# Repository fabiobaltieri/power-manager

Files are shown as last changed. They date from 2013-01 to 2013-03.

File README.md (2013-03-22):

USB Power Manager
=================

http://fabiobaltieri.com/2013/03/22/power-manager/

This project is an USB power controller, and allows to control the power lines
of two USB ports and a generic supply line.

Main features:
- Two controllable USB ports (5V)
- One controllable generic supply line, up to 26V
- Overcurrent protection for USB ports
- Voltage and current measurement on both USB and power ports, before and after
  the switch
- Two additional independent relay lines (for switch simulation)
- Programmable delayed switching sequence for all ports

License
-------

This program is free software: you can redistribute it and/or modify
it under the terms of the GNU General Public License as published by
the Free Software Foundation, either version 2 of the License, or
(at your option) any later version.

Contents
--------

    COPYING      text version of the GPL
    README       this file
    bootloader/  source directory for bootloader
    bootloader-util/ source directory for bootloader utility (bootloadHID)
    commandline/ source directory for the "pm" utility
    firmware/    source directory for main firmware
    hardware/    source directory for the hardware design

Firmware and Bootloader
-----------------------

Building requires an avr-gcc toolchain, in the firmware/ or bootloader/
directory, to build run:

    make

Flashing the firmware on the device requires avrdude and a compatible hardware
programmer. Default configuration is stored at the beginning of the Makefile.
To program with the default configuration, run:

    make flash

Fuses can be configured running:

    make fuses

To program the main firmware from the bootloader, use the command:

    make boot

Hardware
--------

All hardware files (schematic, layout and libraries) are in CadSoft Eagle
format.

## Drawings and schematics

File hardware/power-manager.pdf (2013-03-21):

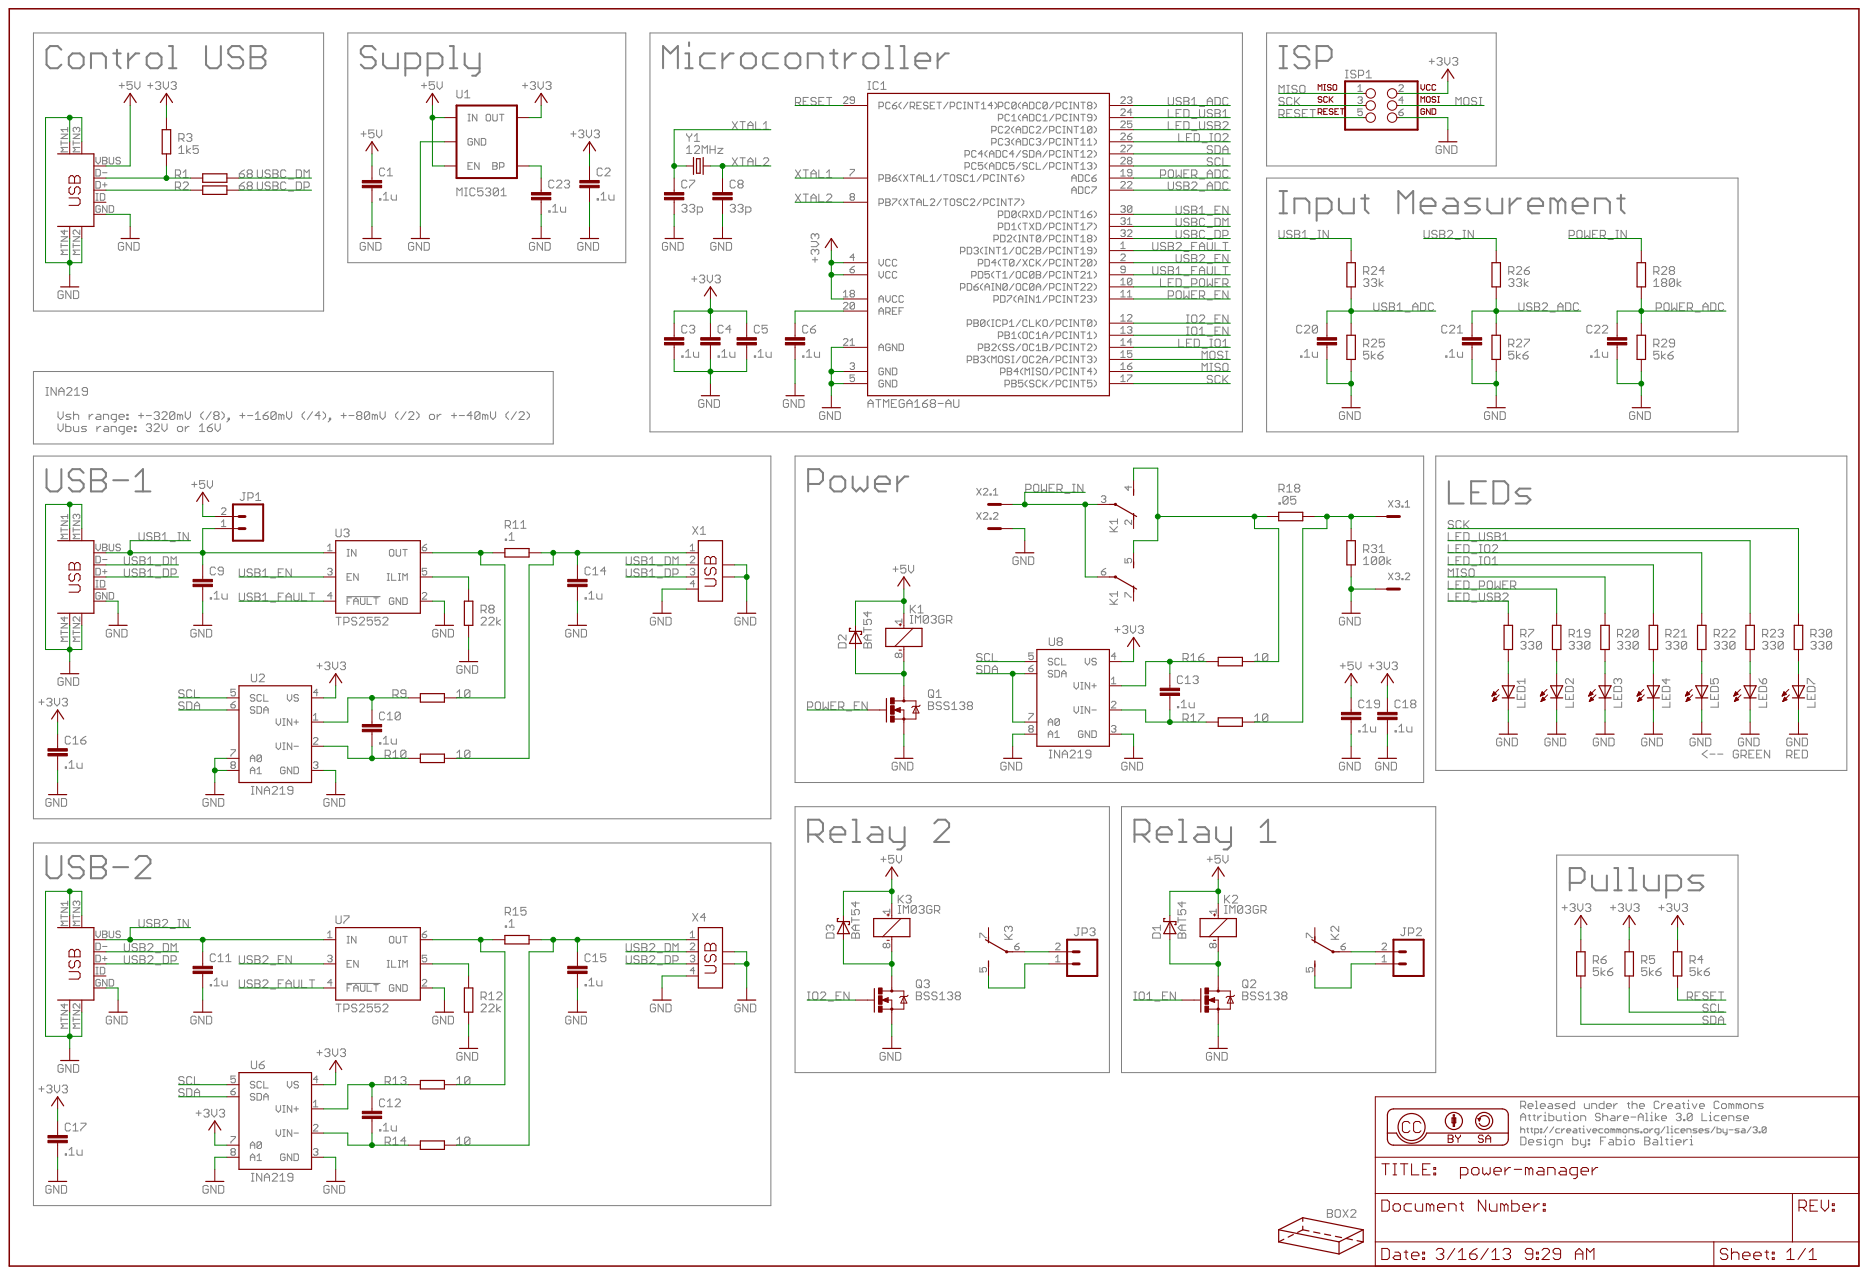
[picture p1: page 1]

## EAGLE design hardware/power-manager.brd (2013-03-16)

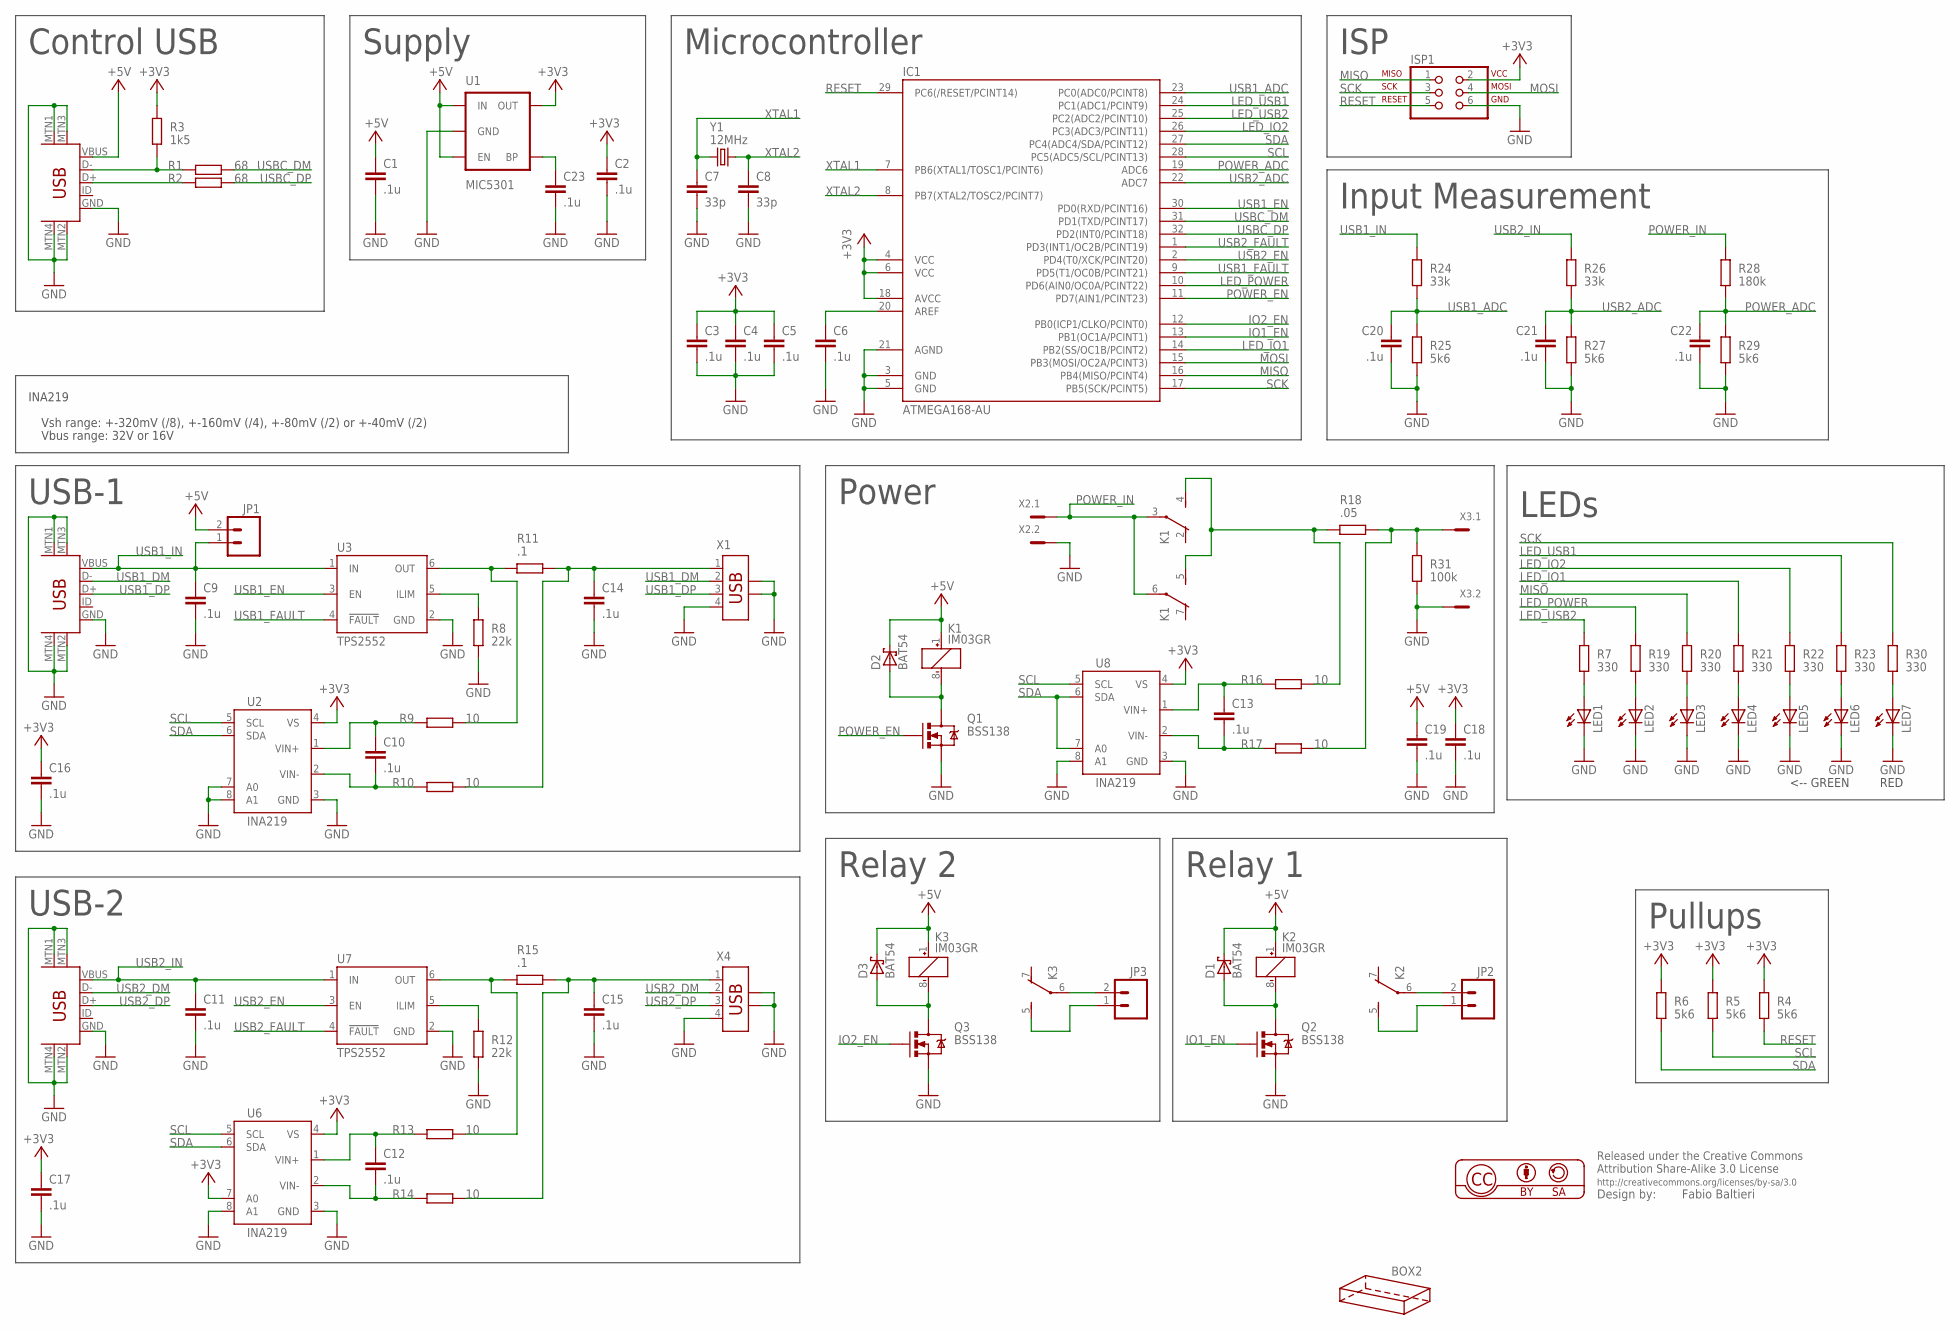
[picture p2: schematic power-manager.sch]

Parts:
BOX2: HAMMOND-BOX-K; 1551K
C1, C2, C3, C4, C5, C6, C9, C10, C11, C12, C13, C14, C15, C16, C17, C18, C19, C20, C21, C22, C23: .1u; C0805
C7, C8: 33p; C0805
D1, D2, D3: BAT54; SOT23
IC1: ATMEGA168-AU; TQFP32-08
ISP1: ISP-AVR910PTH; 2X03
JP1, JP2, JP3: M02PTH; 1X02
K1, K2, K3: IM03GR; G6J-2FL-Y
LED1, LED2, LED3, LED4, LED5, LED6, LED7: LEDSML0805; SML0805
Q1, Q2, Q3: BSS138; SOT23-3
R1, R2: 68; R0603
R3: 1k5; R0603
R4, R5, R6, R25, R27, R29: 5k6; R0603
R7, R19, R20, R21, R22, R23, R30: 330; R0603
R8, R12: 22k; R0603
R9, R10, R13, R14, R16, R17: 10; R0603
R11, R15: .1; R0805
R18: .05; R0805
R24, R26: 33k; R0603
R28: 180k; R0603
R31: 100k; R0603
U1: MIC5301; SOT23-5
U2, U6, U8: INA219; SOT23-8L
U3, U7: TPS2552; SOT23-6L
U$1, U$2, U$3: USB-MINIB-5PIN; USB-MINIB
X1, X4: USB-787616; USB
X2, X3: MC2
Y1: 12MHz; CRYSTAL-SMD-5X3

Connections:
+3V3: C2.1, C3.1, C4.1, C5.1, C16.1, C17.1, C18.1, IC1.4 (VCC), IC1.6 (VCC), IC1.18 (AVCC), ISP1.2, R3.1, R4.1, R5.1, R6.1, U1.5 (OUT), U2.4 (VS), U6.4 (VS), U6.7 (A0), U8.4 (VS)
+5V: C1.1, C19.1, D1.3 (C), D2.3 (C), D3.3 (C), JP1.2, K1.1 (+), K2.1 (+), K3.1 (+), U1.1 (IN), U1.3 (EN), U$1.VBUS
GND: C1.2, C2.2, C3.2, C4.2, C5.2, C6.2, C7.2, C8.2, C9.2, C11.2, C14.2, C15.2, C16.2, C17.2, C18.2, C19.2, C20.2, C21.2, C22.2, C23.2, IC1.3 (GND), IC1.5 (GND), IC1.21 (AGND), ISP1.6, LED1.C, LED2.C, LED3.C, LED4.C, LED5.C, LED6.C, LED7.C, Q1.2 (S), Q2.2 (S), Q3.2 (S), R8.2, R12.2, R25.2, R27.2, R29.2, R31.2, U1.2 (GND), U2.3 (GND), U2.7 (A0), U2.8 (A1), U3.2 (GND), U6.3 (GND), U6.8 (A1), U7.2 (GND), U8.3 (GND), U8.8 (A1), U$1.GND, U$1.MTN1 (MTN2), U$1.MTN2 (MTN3), U$1.MTN3 (MTN1), U$1.MTN4, U$2.GND, U$2.MTN1 (MTN2), U$2.MTN2 (MTN3), U$2.MTN3 (MTN1), U$2.MTN4, U$3.GND, U$3.MTN1 (MTN2), U$3.MTN2 (MTN3), U$3.MTN3 (MTN1), U$3.MTN4, X1.4, X1.SHLD1, X1.SHLD2, X2.2, X3.2, X4.4, X4.SHLD1, X4.SHLD2
IO1_EN: IC1.13 (PB1(OC1A/PCINT1)), Q2.1 (G)
IO2_EN: IC1.12 (PB0(ICP1/CLKO/PCINT0)), Q3.1 (G)
LED_IO1: IC1.14 (PB2(SS/OC1B/PCINT2)), R21.1
LED_IO2: IC1.26 (PC3(ADC3/PCINT11)), R22.1
LED_POWER: IC1.10 (PD6(AIN0/OC0A/PCINT22)), R19.1
LED_USB1: IC1.24 (PC1(ADC1/PCINT9)), R23.1
LED_USB2: IC1.25 (PC2(ADC2/PCINT10)), R7.1
MISO: IC1.16 (PB4(MISO/PCINT4)), ISP1.1, R20.1
MOSI: IC1.15 (PB3(MOSI/OC2A/PCINT3)), ISP1.4
unnamed: R1.1, R3.2, U$1.D-
unnamed: C6.1, IC1.20 (AREF)
unnamed: R2.1, U$1.D+
unnamed: R8.1, U3.5 (ILIM)
unnamed: C23.1, U1.4 (BP)
unnamed: C10.2, R10.1, U2.2 (VIN-)
unnamed: C10.1, R9.1, U2.1 (VIN+)
unnamed: R9.2, R11.1, U3.6 (OUT)
unnamed: C14.1, R10.2, R11.2, X1.1
unnamed: LED7.A, R30.2
unnamed: R12.1, U7.5 (ILIM)
unnamed: C12.2, R14.1, U6.2 (VIN-)
unnamed: C12.1, R13.1, U6.1 (VIN+)
unnamed: R13.2, R15.1, U7.6 (OUT)
unnamed: C15.1, R14.2, R15.2, X4.1
unnamed: C13.2, R17.1, U8.2 (VIN-)
unnamed: C13.1, R16.1, U8.1 (VIN+)
unnamed: K1.4 (S), K1.5 (S), R16.2, R18.1
unnamed: R17.2, R18.2, R31.1, X3.1
unnamed: D2.1 (A), K1.8 (-), Q1.3 (D)
unnamed: D1.1 (A), K2.8 (-), Q2.3 (D)
unnamed: JP2.2, K2.6
unnamed: JP2.1, K2.5 (S)
unnamed: D3.1 (A), K3.8 (-), Q3.3 (D)
unnamed: JP3.2, K3.6
unnamed: JP3.1, K3.5 (S)
unnamed: LED1.A, R7.2
unnamed: LED2.A, R19.2
unnamed: LED3.A, R20.2
unnamed: LED4.A, R21.2
unnamed: LED5.A, R22.2
unnamed: LED6.A, R23.2
POWER_ADC: C22.1, IC1.19 (ADC6), R28.2, R29.1
POWER_EN: IC1.11 (PD7(AIN1/PCINT23)), Q1.1 (G)
POWER_IN: K1.3, K1.6, R28.1, X2.1
RESET: IC1.29 (PC6(/RESET/PCINT14)), ISP1.5, R4.2
SCK: IC1.17 (PB5(SCK/PCINT5)), ISP1.3, R30.1
SCL: IC1.28 (PC5(ADC5/SCL/PCINT13)), R5.2, U2.5 (SCL), U6.5 (SCL), U8.5 (SCL)
SDA: IC1.27 (PC4(ADC4/SDA/PCINT12)), R6.2, U2.6 (SDA), U6.6 (SDA), U8.6 (SDA), U8.7 (A0)
USB1_ADC: C20.1, IC1.23 (PC0(ADC0/PCINT8)), R24.2, R25.1
USB1_DM: U$2.D-, X1.2
USB1_DP: U$2.D+, X1.3
USB1_EN: IC1.30 (PD0(RXD/PCINT16)), U3.3 (EN)
USB1_FAULT: IC1.9 (PD5(T1/OC0B/PCINT21)), U3.4 (!FAULT)
USB1_IN: C9.1, JP1.1, R24.1, U3.1 (IN), U$2.VBUS
USB2_ADC: C21.1, IC1.22 (ADC7), R26.2, R27.1
USB2_DM: U$3.D-, X4.2
USB2_DP: U$3.D+, X4.3
USB2_EN: IC1.2 (PD4(T0/XCK/PCINT20)), U7.3 (EN)
USB2_FAULT: IC1.1 (PD3(INT1/OC2B/PCINT19)), U7.4 (!FAULT)
USB2_IN: C11.1, R26.1, U7.1 (IN), U$3.VBUS
USBC_DM: IC1.31 (PD1(TXD/PCINT17)), R1.2
USBC_DP: IC1.32 (PD2(INT0/PCINT18)), R2.2
XTAL1: C7.1, IC1.7 (PB6(XTAL1/TOSC1/PCINT6)), Y1.1
XTAL2: C8.1, IC1.8 (PB7(XTAL2/TOSC2/PCINT7)), Y1.3 (2)

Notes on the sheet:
Microcontroller
Control USB
USB-1
USB-2
Power
Supply
Relay 1
Relay 2
ISP
Pullups
LEDs
INA219
Vsh range: +-320mV (/8), +-160mV (/4), +-80mV (/2) or +-40mV (/2)
Vbus range: 32V or 16V
Input Measurement
RED
<-- GREEN

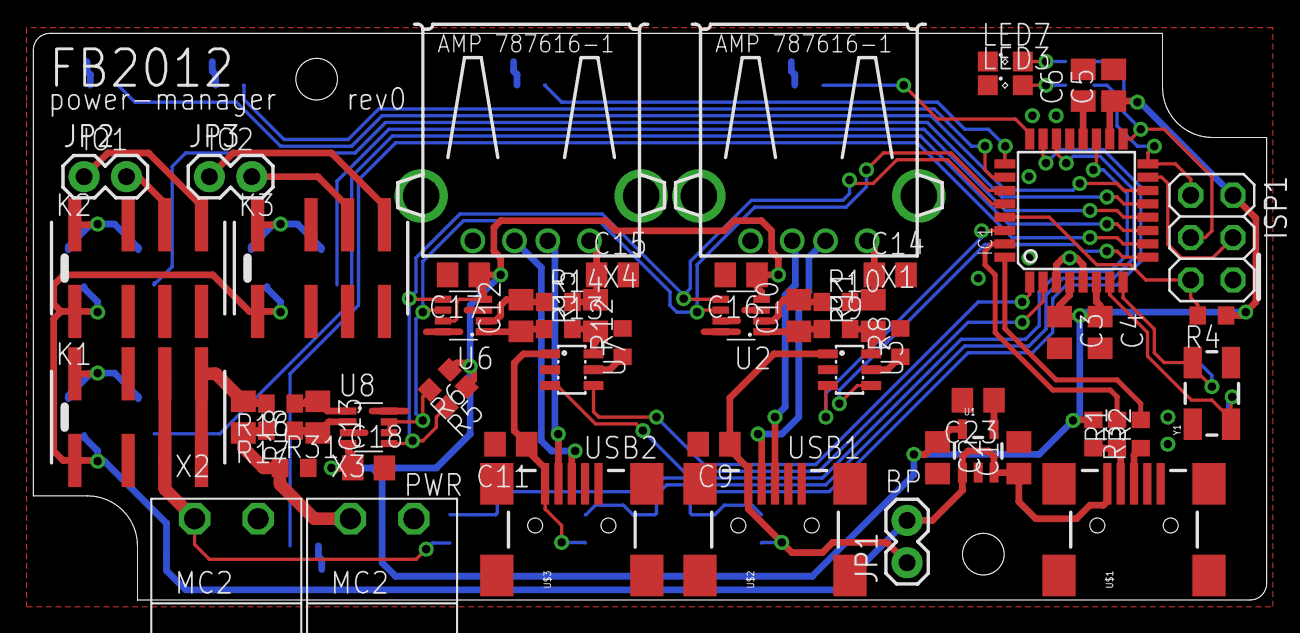
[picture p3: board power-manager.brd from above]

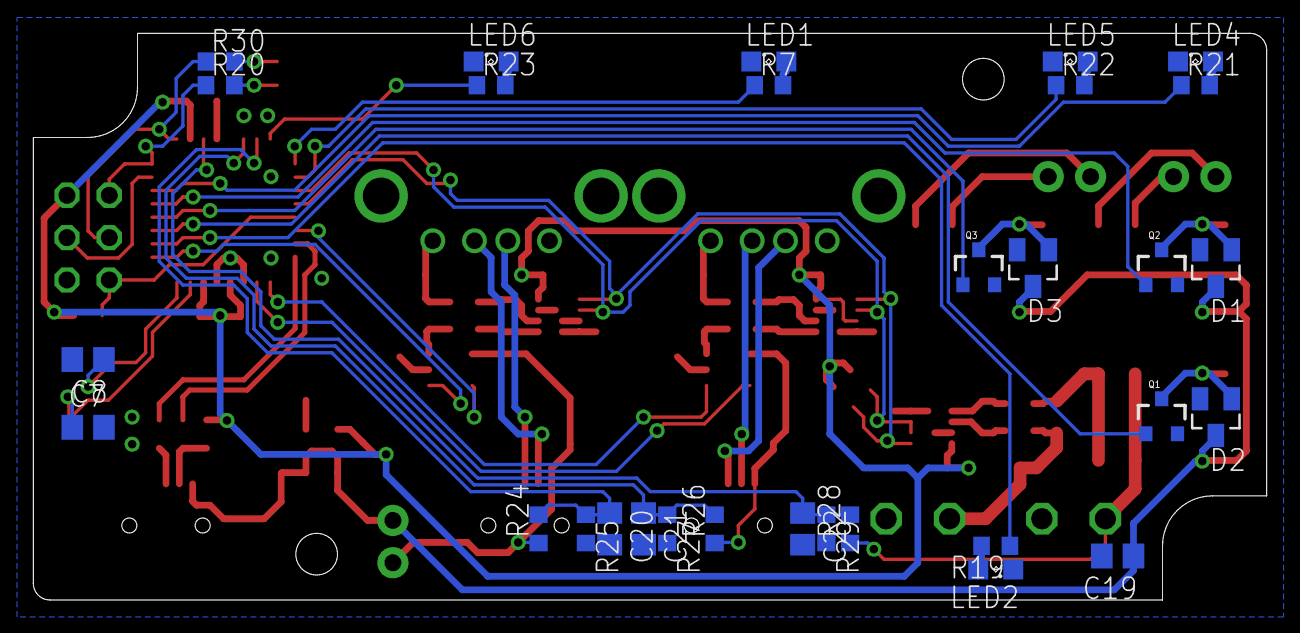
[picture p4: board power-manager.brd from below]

Board: 2 copper layers, 74.0 x 34.0 mm, 90 parts (30 on the bottom side), 67 nets.

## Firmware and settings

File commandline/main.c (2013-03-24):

/*
 * Copyright 2013 Fabio Baltieri (fabio.baltieri@gmail.com)
 *
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
 */
#include <stdio.h>
#include <stdlib.h>
#include <string.h>
#include <stdint.h>
#include <unistd.h>
#include <fcntl.h>
#include <sys/stat.h>
#include <sys/types.h>
#include <endian.h>

#include <libusb.h>

#include "../firmware/requests.h"

#define VENDOR_ID 0x1d50
#define PRODUCT_ID 0x6061

static void send_reset(libusb_device_handle *usbdev)
{
	int ret;

	ret = libusb_control_transfer(usbdev,
			LIBUSB_REQUEST_TYPE_VENDOR |
			LIBUSB_RECIPIENT_DEVICE |
			LIBUSB_ENDPOINT_IN,
			CUSTOM_RQ_RESET,
			0, 0, NULL, 0, 1000);

	if (ret < 0) {
		printf("libusb_control_transfer: %s\n", libusb_error_name(ret));
		exit(1);
	}
}

static void send_clear(libusb_device_handle *usbdev)
{
	int ret;

	ret = libusb_control_transfer(usbdev,
			LIBUSB_REQUEST_TYPE_VENDOR |
			LIBUSB_RECIPIENT_DEVICE |
			LIBUSB_ENDPOINT_IN,
			CUSTOM_RQ_EV_CLEAR,
			0, 0, NULL,0, 1000);

	if (ret < 0) {
		printf("libusb_control_transfer: %s\n", libusb_error_name(ret));
		exit(1);
	}
}

static void show_status(libusb_device_handle *usbdev)
{
	int ret;
	struct usb_status status;

	ret = libusb_control_transfer(usbdev,
			      LIBUSB_REQUEST_TYPE_VENDOR |
			      LIBUSB_RECIPIENT_DEVICE |
			      LIBUSB_ENDPOINT_IN,
			      CUSTOM_RQ_STATUS,
			      0, 0,
			      (unsigned char *)&status, sizeof(status), 1000);

	if (ret < 0) {
		printf("libusb_control_transfer: %s\n", libusb_error_name(ret));
		exit(1);
	}

	/* print status */
	printf("              USB1%c  USB2%c POWER%c   IO1%c   IO2%c\n",
	       (status.state & PM_CH_USB1) ? '*' : ' ',
	       (status.state & PM_CH_USB2) ? '*' : ' ',
	       (status.state & PM_CH_POWER) ? '*' : ' ',
	       (status.state & PM_CH_IO1) ? '*' : ' ',
	       (status.state & PM_CH_IO2) ? '*' : ' ');
	printf(" voltage_in: %6hd %6hd %6hd\n",
	       le16toh(status.voltage_in[0]),
	       le16toh(status.voltage_in[1]),
	       le16toh(status.voltage_in[2]));
	printf("voltage_out: %6hd %6hd %6hd\n",
	       le16toh(status.voltage_out[0]),
	       le16toh(status.voltage_out[1]),
	       le16toh(status.voltage_out[2]));
	printf("    current: %6hd %6hd %6hd\n",
	       le16toh(status.current[0]),
	       le16toh(status.current[1]),
	       le16toh(status.current[2]));
	printf("      power: %6hd %6hd %6hd\n",
	       le16toh(status.power[0]),
	       le16toh(status.power[1]),
	       le16toh(status.power[2]));
	printf("       fail: %02x\n", status.fail);
}

static void send_event(libusb_device_handle *usbdev,
		       int delay, int mask, int value)
{
	int ret;
	uint16_t usb_index;
	uint16_t usb_value;

	usb_index = delay & 0xffff;
	usb_value = ((mask & 0xff) << 8) | (value & 0xff);

	ret = libusb_control_transfer(usbdev,
			LIBUSB_REQUEST_TYPE_VENDOR |
			LIBUSB_RECIPIENT_DEVICE |
			LIBUSB_ENDPOINT_IN,
			CUSTOM_RQ_EV_PUSH,
			usb_index, usb_value,
			NULL, 0, 1000);

	if (ret < 0) {
		printf("libusb_control_transfer: %s\n", libusb_error_name(ret));
		exit(1);
	}
}

static void usage(char *name)
{
	fprintf(stderr, "Usage: %s -h\n", name);
	fprintf(stderr, "       %s -R\n", name);
	fprintf(stderr, "       %s [options]\n", name);
	fprintf(stderr, "options:\n"
			"  -h         this help\n"
			"  -R         reset device\n"
			"  -s         show status\n"
			"  -w         wait delay in tenth of seconds\n"
			"  -C         clear event queue\n"
			"  -e list    enable listed i/o (comma separated)\n"
			"  -d list    disable listed i/o (comma separated)\n"
			"\n"
			"valid i/o: usb1,usb2,power,io1,io2,all\n"
			);
	exit(1);
}

static int parse_io(char *str)
{
	int ret = 0;
	char *tk;

	while ((tk = strtok(str, ",;:")) != NULL) {
		if (strcmp(tk, "usb1") == 0) {
			ret |= PM_CH_USB1;
		} else if (strcmp(tk, "usb2") == 0) {
			ret |= PM_CH_USB2;
		} else if (strcmp(tk, "power") == 0) {
			ret |= PM_CH_POWER;
		} else if (strcmp(tk, "io1") == 0) {
			ret |= PM_CH_IO1;
		} else if (strcmp(tk, "io2") == 0) {
			ret |= PM_CH_IO2;
		} else if (strcmp(tk, "all") == 0) {
			ret |= PM_CH_USB1 | PM_CH_USB2 |
				PM_CH_POWER |
				PM_CH_IO1 | PM_CH_IO2;
		} else {
			printf("unknown i/o: %s\n", tk);
		}
		str = NULL;
	}

	return ret;
}

int main(int argc, char **argv)
{
	libusb_context *ctx;
	libusb_device_handle *usbdev;
	int opt;
	int reset = 0;
	int status = 0;
	int mask = 0;
	int value = 0;
	int delay = 0;
	int clear = 0;
	int tmp;

	libusb_init(&ctx);

	while ((opt = getopt(argc, argv, "hRCse:d:w:")) != -1) {
		switch (opt) {
		case 'h':
			usage(argv[0]);
			break;
		case 'R':
			reset = 1;
			break;
		case 'C':
			clear = 1;
			break;
		case 's':
			status = 1;
			break;
		case 'w':
			delay = strtol(optarg, NULL, 0);
			break;
		case 'e':
			tmp = parse_io(optarg);
			value |= tmp;
			mask |= tmp;
			break;
		case 'd':
			tmp = parse_io(optarg);
			value &= ~tmp;
			mask |= tmp;
			break;
		default:
			usage(argv[0]);
		}
	}

	usbdev = libusb_open_device_with_vid_pid(ctx, VENDOR_ID, PRODUCT_ID);
	if (!usbdev) {
		fprintf(stderr, "error: could not find USB device %04x:%04x\n",
				VENDOR_ID, PRODUCT_ID);
		exit(1);
	}

	if (reset) {
		send_reset(usbdev);
		return 0;
	}

	if (clear)
		send_clear(usbdev);

	if (status)
		show_status(usbdev);

	if (mask)
		send_event(usbdev, delay, mask, value);

	libusb_close(usbdev);

	libusb_exit(ctx);

	return 0;
}

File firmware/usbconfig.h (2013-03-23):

/* Name: usbconfig.h
 * Project: V-USB, virtual USB port for Atmel's(r) AVR(r) microcontrollers
 * Author: Christian Starkjohann
 * Creation Date: 2005-04-01
 * Tabsize: 4
 * Copyright: (c) 2005 by OBJECTIVE DEVELOPMENT Software GmbH
 * License: GNU GPL v2 (see License.txt), GNU GPL v3 or proprietary (CommercialLicense.txt)
 * This Revision: $Id$
 */

#ifndef __usbconfig_h_included__
#define __usbconfig_h_included__

/*
General Description:
This file is an example configuration (with inline documentation) for the USB
driver. It configures V-USB for USB D+ connected to Port D bit 2 (which is
also hardware interrupt 0 on many devices) and USB D- to Port D bit 4. You may
wire the lines to any other port, as long as D+ is also wired to INT0 (or any
other hardware interrupt, as long as it is the highest level interrupt, see
section at the end of this file).
+ To create your own usbconfig.h file, copy this file to your project's
+ firmware source directory) and rename it to "usbconfig.h".
+ Then edit it accordingly.
*/

/* ---------------------------- Hardware Config ---------------------------- */

#define USB_CFG_IOPORTNAME      D
/* This is the port where the USB bus is connected. When you configure it to
 * "B", the registers PORTB, PINB and DDRB will be used.
 */
#define USB_CFG_DMINUS_BIT      1
/* This is the bit number in USB_CFG_IOPORT where the USB D- line is connected.
 * This may be any bit in the port.
 */
#define USB_CFG_DPLUS_BIT       2
/* This is the bit number in USB_CFG_IOPORT where the USB D+ line is connected.
 * This may be any bit in the port. Please note that D+ must also be connected
 * to interrupt pin INT0! [You can also use other interrupts, see section
 * "Optional MCU Description" below, or you can connect D- to the interrupt, as
 * it is required if you use the USB_COUNT_SOF feature. If you use D- for the
 * interrupt, the USB interrupt will also be triggered at Start-Of-Frame
 * markers every millisecond.]
 */
#define USB_CFG_CLOCK_KHZ       (F_CPU/1000)
/* Clock rate of the AVR in kHz. Legal values are 12000, 12800, 15000, 16000,
 * 16500, 18000 and 20000. The 12.8 MHz and 16.5 MHz versions of the code
 * require no crystal, they tolerate +/- 1% deviation from the nominal
 * frequency. All other rates require a precision of 2000 ppm and thus a
 * crystal!
 * Since F_CPU should be defined to your actual clock rate anyway, you should
 * not need to modify this setting.
 */
#define USB_CFG_CHECK_CRC       0
/* Define this to 1 if you want that the driver checks integrity of incoming
 * data packets (CRC checks). CRC checks cost quite a bit of code size and are
 * currently only available for 18 MHz crystal clock. You must choose
 * USB_CFG_CLOCK_KHZ = 18000 if you enable this option.
 */

/* ----------------------- Optional Hardware Config ------------------------ */

/* #define USB_CFG_PULLUP_IOPORTNAME   D */
/* If you connect the 1.5k pullup resistor from D- to a port pin instead of
 * V+, you can connect and disconnect the device from firmware by calling
 * the macros usbDeviceConnect() and usbDeviceDisconnect() (see usbdrv.h).
 * This constant defines the port on which the pullup resistor is connected.
 */
/* #define USB_CFG_PULLUP_BIT          4 */
/* This constant defines the bit number in USB_CFG_PULLUP_IOPORT (defined
 * above) where the 1.5k pullup resistor is connected. See description
 * above for details.
 */

/* --------------------------- Functional Range ---------------------------- */
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

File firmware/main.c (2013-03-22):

/*
 * Copyright 2013 Fabio Baltieri (fabio.baltieri@gmail.com)
 *
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
 */

#include <avr/io.h>
#include <avr/wdt.h>
#include <avr/interrupt.h>
#include <util/delay.h>

#include "usbdrv.h"

#include "board.h"
#include "requests.h"
#include "jiffies.h"
#include "io.h"
#include "events.h"
#include "adc.h"
#include "i2c.h"
#include "ina219.h"

#define div_round(a, b) (((a) + ((b)/2)) / (b))

static struct usb_status status;

static void reset_cpu(void)
{
	wdt_disable();

	wdt_enable(WDTO_15MS);

	for (;;);
}

static uint16_t get_millivolts(uint8_t chan, uint32_t num, uint32_t den)
{
	adc_set_channel(get_adc_ch(chan));

	_delay_us(200);

	return div_round((uint32_t)adc_get_value() * 1100 * num,
			 (uint32_t)1024 * den);
}

static void update_status(void)
{
	int16_t val;

	status.fail = (read_fault(CHANNEL_USB1) ? 1 : 0) |
		(read_fault(CHANNEL_USB2) ? 2 : 0);

	status.voltage_in[0] = get_millivolts(CHANNEL_USB1,
					      USB_N, USB_D);
	status.voltage_in[1] = get_millivolts(CHANNEL_USB2,
					      USB_N, USB_D);
	status.voltage_in[2] = get_millivolts(CHANNEL_POWER,
					      POWER_N, POWER_D);

	val = i2c_read_word(get_addr(CHANNEL_USB1), INA2XX_BUS_VOLTAGE);
	val = (val >> INA219_BUS_VOLTAGE_SHIFT) * INA219_BUS_VOLTAGE_LSB;
	status.voltage_out[0] = val;

	val = i2c_read_word(get_addr(CHANNEL_USB2), INA2XX_BUS_VOLTAGE);
	val = (val >> INA219_BUS_VOLTAGE_SHIFT) * INA219_BUS_VOLTAGE_LSB;
	status.voltage_out[1] = val;

	val = i2c_read_word(get_addr(CHANNEL_POWER), INA2XX_BUS_VOLTAGE);
	val = (val >> INA219_BUS_VOLTAGE_SHIFT) * INA219_BUS_VOLTAGE_LSB;
	status.voltage_out[2] = val;

	val = i2c_read_word(get_addr(CHANNEL_USB1), INA2XX_CURRENT);
	status.current[0] = val;

	val = i2c_read_word(get_addr(CHANNEL_USB2), INA2XX_CURRENT);
	status.current[1] = val;

	val = i2c_read_word(get_addr(CHANNEL_POWER), INA2XX_CURRENT);
	status.current[2] = val;

	val = i2c_read_word(get_addr(CHANNEL_USB1), INA2XX_POWER);
	status.power[0] = val * INA219_POWER_LSB;

	val = i2c_read_word(get_addr(CHANNEL_USB2), INA2XX_POWER);
	status.power[1] = val * INA219_POWER_LSB;

	val = i2c_read_word(get_addr(CHANNEL_POWER), INA2XX_POWER);
	status.power[2] = val * INA219_POWER_LSB;
}

usbMsgLen_t usbFunctionSetup(uint8_t data[8])
{
	struct usbRequest *rq = (void *)data;
	struct event ev;

	switch (rq->bRequest) {
	case CUSTOM_RQ_STATUS:
		update_status();
		usbMsgPtr = (uint8_t *)&status;
		return sizeof(status);
	case CUSTOM_RQ_EV_CLEAR:
		ev_reset();
		break;
	case CUSTOM_RQ_EV_PUSH:
		if (ev_count() == 0) {
			/* start from current time */
			ev.ts = jiffies + rq->wValue.word;
		} else {
			/* start from last event */
			struct event *tmp = ev_last();
			ev.ts = tmp->ts + rq->wValue.word;
		}
		ev.mask = rq->wIndex.bytes[1];
		ev.value = rq->wIndex.bytes[0];
		ev_push(&ev);
		break;
	case CUSTOM_RQ_RESET:
		reset_cpu();
		break;
	default:
		/* do nothing */
		;
	}

	return 0;
}

static void check_io(struct event *ev, uint8_t mask, uint8_t ch)
{
	if (ev->mask & mask) {
		if (ev->value & mask) {
			set_led(ch, 1);
			set_en(ch, 1);
			status.state |= (1 << ch);
		} else {
			set_en(ch, 0);
			set_led(ch, 0);
			status.state &= ~(1 << ch);
		}
	}
}

#define time_after(a, b) ((int16_t)b - (int16_t)a > 0)
static void event_poll(void)
{
	static uint16_t holdoff = 0;
	struct event *ev;

	/* status LEDs */
	if (ev_count()) {
		led_a_off();
		if (time_after(jiffies, holdoff))
			led_b_off();
		else
			led_b_on();
	} else {
		led_a_on();
		led_b_off();
		holdoff = jiffies;
	}

	/* event processing */
	while (ev_count()) {
		ev = ev_first();

		if (time_after(jiffies, ev->ts))
			return;

		check_io(ev, PM_CH_USB1, CHANNEL_USB1);
		check_io(ev, PM_CH_USB2, CHANNEL_USB2);
		check_io(ev, PM_CH_POWER, CHANNEL_POWER);
		check_io(ev, PM_CH_IO1, CHANNEL_IO1);
		check_io(ev, PM_CH_IO2, CHANNEL_IO2);

		ev_drop_first();

		holdoff = jiffies + 5;
	}
}

static void hello(void)
{
	uint8_t i;

	for (i = 0; i < 8; i++) {
		led_a_toggle();
		led_b_toggle();
		_delay_ms(50);
	}
}

void ina_init(void)
{
	/* USB 1 */
	i2c_write_word(get_addr(CHANNEL_USB1), INA2XX_CONFIG,
		       INA219_CONFIG_DEFAULT);
	i2c_write_word(get_addr(CHANNEL_USB1), INA2XX_CALIBRATION,
		       INA219_CALIBRATION_FACT / RSHUNT_USB);
	/* USB 2 */
	i2c_write_word(get_addr(CHANNEL_USB2), INA2XX_CONFIG,
		       INA219_CONFIG_DEFAULT);
	i2c_write_word(get_addr(CHANNEL_USB2), INA2XX_CALIBRATION,
		       INA219_CALIBRATION_FACT / RSHUNT_USB);
	/* POWER */
	i2c_write_word(get_addr(CHANNEL_POWER), INA2XX_CONFIG,
		       INA219_CONFIG_DEFAULT);
	i2c_write_word(get_addr(CHANNEL_POWER), INA2XX_CALIBRATION,
		       INA219_CALIBRATION_FACT / RSHUNT_POWER);
}

int __attribute__((noreturn)) main(void)
{
	uint8_t i;

	led_init();

	adc_init();
	i2c_init(400000);
	ina_init();

	io_init();
	ev_reset();

	wdt_enable(WDTO_1S);

	hello();
	led_a_on();
	led_b_off();

	jiffies_init();

	usbInit();
	usbDeviceDisconnect();

	i = 0;
	while (--i) {
		wdt_reset();
		_delay_ms(1);
	}

	usbDeviceConnect();

	sei();
	for (;;) {
		wdt_reset();
		usbPoll();
		event_poll();
	}
}

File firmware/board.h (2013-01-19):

/* LEDs */

#define LED_A_PORT    PORTB
#define LED_A_DDR     DDRB
#define LED_A         PB4

#define LED_B_PORT    PORTB
#define LED_B_DDR     DDRB
#define LED_B         PB5

#define led_a_on()     LED_A_PORT |=  _BV(LED_A)
#define led_a_off()    LED_A_PORT &= ~_BV(LED_A)
#define led_a_toggle() LED_A_PORT ^=  _BV(LED_A)

#define led_b_on()     LED_B_PORT |=  _BV(LED_B)
#define led_b_off()    LED_B_PORT &= ~_BV(LED_B)
#define led_b_toggle() LED_B_PORT ^=  _BV(LED_B)

#define led_init()				\
	do {					\
		LED_A_DDR |= _BV(LED_A);	\
		LED_B_DDR |= _BV(LED_B);	\
	} while (0);

/* ADC */

#define USB_PARTITOR_H		330	/* 33k */
#define USB_PARTITOR_L		56	/* 5k6 */
#define POWER_PARTITOR_H	1800	/* 180k */
#define POWER_PARTITOR_L	56	/* 5k6 */

#define USB_N	(USB_PARTITOR_L + USB_PARTITOR_H)
#define USB_D	(USB_PARTITOR_L)
#define POWER_N	(POWER_PARTITOR_H + POWER_PARTITOR_L)
#define POWER_D	(POWER_PARTITOR_L)

/* Shunt */
#define RSHUNT_USB	100000	/* 100 mOhm */
#define RSHUNT_POWER	50000	/* 50 mOhm */

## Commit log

2012-11-08 hw: rc
    [power-manager.brd, power-manager.sch]
2012-11-08 bl: add bootloader from usb-current-meter
2012-11-08 bl: fix minor warning
    [main.c]
2012-11-10 hw: rc2
    [power-manager.brd, power-manager.sch]
2012-11-10 hw: rc3
    [power-manager.brd, power-manager.sch]
2012-11-10 hw: rc4?
    [power-manager.brd]
2012-11-10 hw: rc5
    [power-manager.brd]
2012-11-10 hw: rc6
    [power-manager.brd]
2012-11-10 hw: rc7
    [power-manager.brd, power-manager.sch]
2012-11-10 hw: rc8
    [power-manager.brd, power-manager.sch]
2012-11-25 hw: update hammond library
    [power-manager.brd, power-manager.sch]
2012-11-30 bootloader: fix GPIO config
    [main.c]
2012-11-30 bl: change clock speed and fuse bytes
2012-11-30 fw: fix led configuration
    [board.h]
2012-11-30 fw: move board include
2012-12-12 fw: config for power-manager board
2013-01-17 board: fix led polarity
    [board.h]
2013-01-17 hw: update part values
    [power-manager.brd, power-manager.sch]
2013-01-17 fw: io: readability fixes
    [io.c]
2013-01-17 fw: jiffies: use correct timer
2013-01-17 fw: board: remove extra ;
2013-01-18 fw: event chain and io working
2013-01-18 fw: io: fix fault reading
    [io.c]
2013-01-18 fw: add adc support
2013-01-18 fw: main: fix led startup sequence
    [main.c]
2013-01-18 fw: board: add partitor values
2013-01-18 fw: main: add adc voltage measurement support function
2013-01-18 fw: adc: remove board include
2013-01-19 fw: add and compile in i2c
2013-01-19 fw: enable i2c and add ina defs
2013-01-19 fw: i2c: swap bytes
    [i2c.c]
2013-01-19 fw: i2c: add dynamic frequency selection
2013-01-19 fw: fix led holdoff bug
    [main.c]
2013-01-20 cmdline: remove debug printf
2013-01-21 cmdline: print line statuses
2013-02-26 hw: add notes and pdf
    [power-manager.brd, power-manager.sch]
2013-03-05 cmdline: add missing newline in help text
    [main.c]
2013-03-16 hw: update xtal cap values to 33p
    [power-manager.brd, power-manager.sch]
2013-03-23 fw: usbconfig: use openmoko's assigned ID
    Change main firmware USB vendor and product IDs to the one assigned in
    the Openmoko registry, that can be found at:
    http://wiki.openmoko.org/wiki/USB_Product_IDs
    Assigned IDs: 0x1d50 0x6061 Power Manager
    Thanks Openmoko!
2013-03-23 cmdline: use vendor/product id to find the device path
    As the project has now an assigned vendor:device pair, use that to find
    the right device instead of the product string.
2013-03-24 cmdline: upgrade USB API to libusb-1.0
    And get rid of the custom vid/pid open in favor of
    libusb_open_device_with_vid_pid.
2013-05-21 fw: allow i2c master read to send nack

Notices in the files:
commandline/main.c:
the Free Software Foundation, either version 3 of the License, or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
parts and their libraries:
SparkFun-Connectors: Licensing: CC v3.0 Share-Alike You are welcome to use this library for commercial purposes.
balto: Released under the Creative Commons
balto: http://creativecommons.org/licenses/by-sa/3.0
